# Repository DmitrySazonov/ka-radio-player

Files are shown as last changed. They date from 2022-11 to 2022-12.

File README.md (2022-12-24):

# ka-radio-player
This is a ka-radio player build project based on the ESP 32 and the UDA1334A DAC. The player uses the micro-usb connection as a power supply and has a mini-jack output for connecting to headphones or speakers.
There are 2 versions of cases in the project: for the screen 0.96" and 2.42".
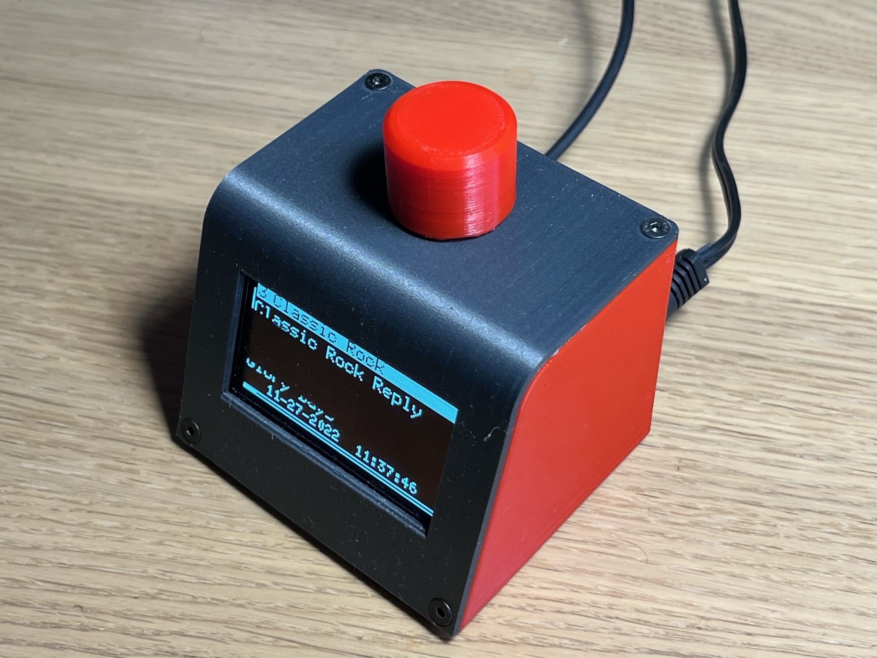
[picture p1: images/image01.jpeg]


V2 version for 2.42 display

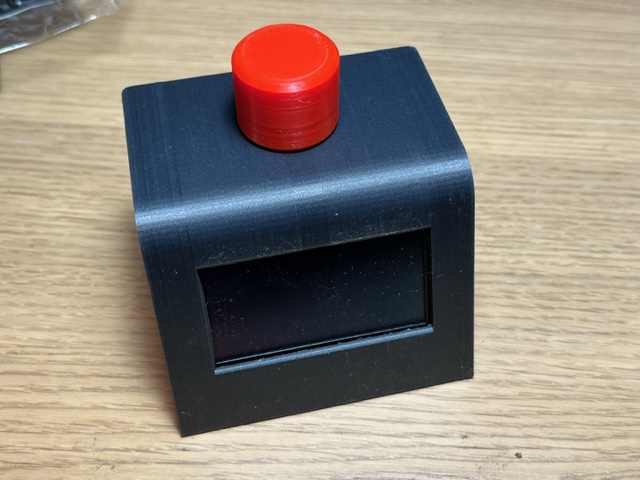
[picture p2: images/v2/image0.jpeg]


Demo video: https://youtu.be/d_xDyBW4TkM

## Components
- ESP 32 38P - https://sl.aliexpress.ru/p?key=cSeExr8
- UDA1334A DAC - https://sl.aliexpress.ru/p?key=o4eExBC
- Digital knob encoder - https://sl.aliexpress.ru/p?key=FfeExsv
- 2.42" OLED 4 pin display - https://sl.aliexpress.ru/p?key=MNKdxjn
or
0.96" OLED 4 pin display - https://sl.aliexpress.ru/p?key=2NeExj4
- 1K resistor

## Principal schema

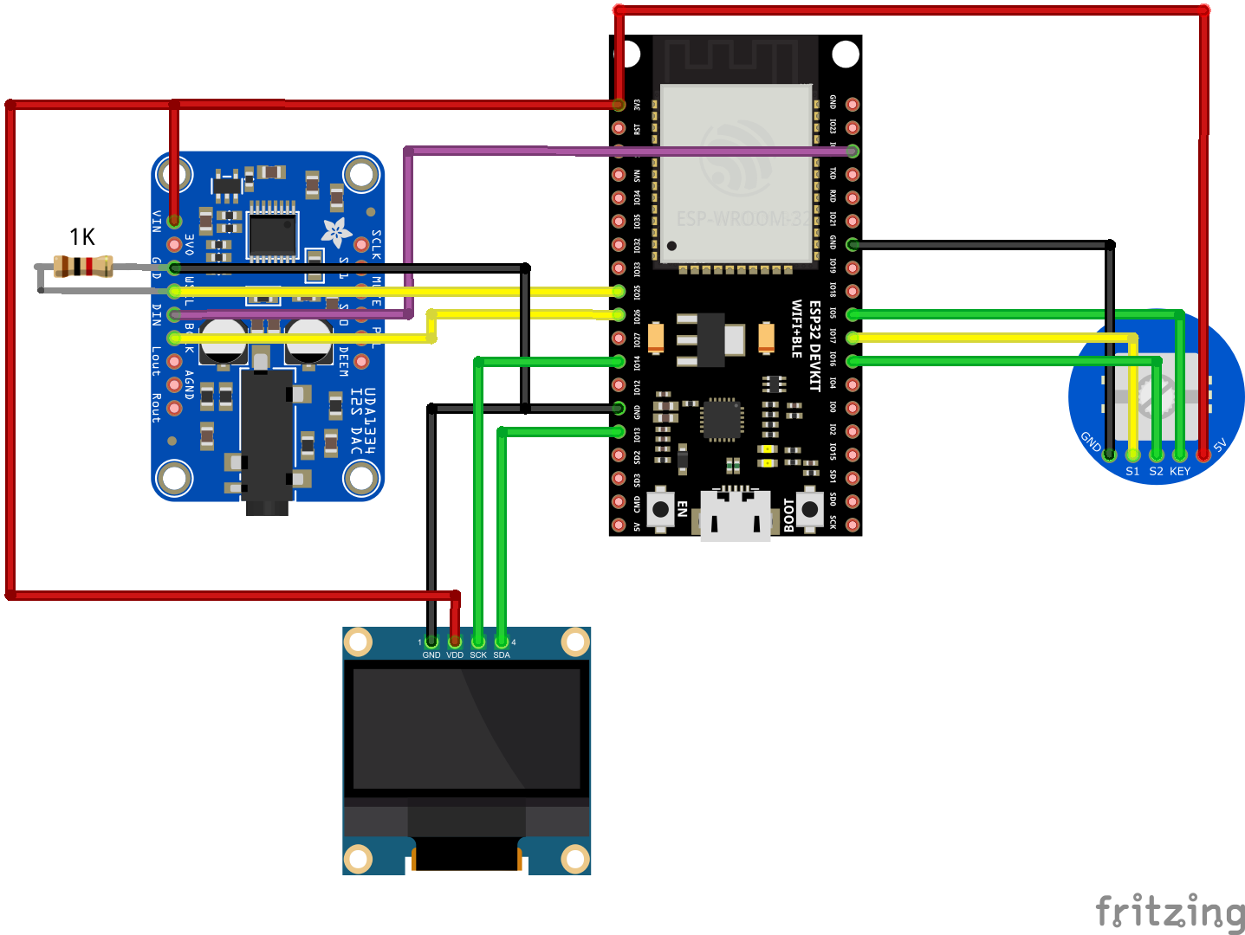
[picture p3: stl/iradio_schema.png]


### UDA1334A connection
| UDA1334A | ESP 32 |
|---|---|
| VIN | 3V3 |
| GND | GND |
| DIN | IO22 |
| WSEL | IO25 |
| BCLK | IO26 |

And add 1K resistor between **WSEL-GND**

### Display connection
| OLED Display | ESP 32 |
|---|---|
| GND | GND |
| VDD / VCC | 3V3 |
| SCK / SLC | IO14 |
| SDA | IO13 |

### Knob encoder connection
| Knob | ESP 32 |
|---|---|
| GND  | GND |
| S1 | IO17 |
| S2 | IO16 |
| KEY  | IO5 |
| 5V | 3V3 |

## 3D Print options

### Printing position
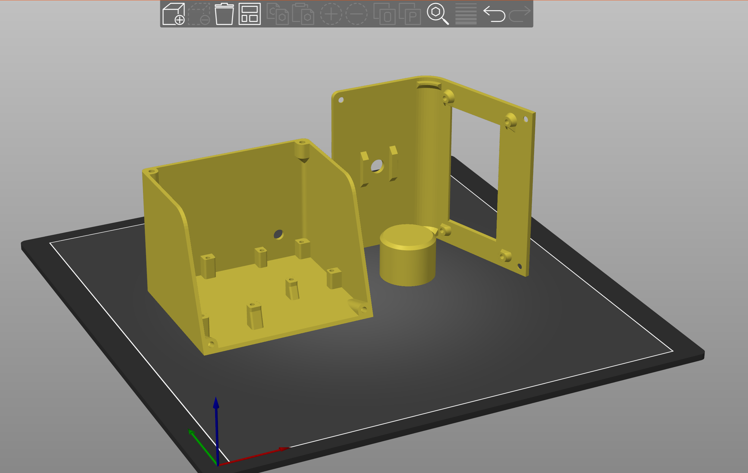
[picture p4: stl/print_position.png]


## Player assembly

The player body is printed on a 3-d printer. Models for printing are in the **/stl** folder, select models according to the size of the display.

For mount used:
- M2.5x5 mm bolt (8pc) to mount the boards
- M3x5 mm bolt (4pc) to mount the cap to case
- M2.5x5 mm bolt (2pc or 4pc) to mount display to cap

For v2 case mount:
- M2.5x5 mm bolt (10pc) to mount the boards and case

## Connection

- Plug the usb charger into the micro-usb. 

**IMPORTANT!** 
It is recommended to use a good quality power supply, especially for the 2.42" display version. I use BASEUS Compact Quick Charger USB+Type-C, 3A, 20W.

- Plug your headphones or speakers (with built-in amplifier) into the mini-jack connector.

## Configuration

The project is based on the firmware [karadio32](https://github.com/karawin/Ka-Radio32)

To flash it, just download the archive from the [release](https://github.com/karawin/Ka-Radio32/releases) page and flash it as specified in the [README](https://github.com/karawin/Ka-Radio32#first-use) of the project.

For more information search for karadio32 guides on the internet.

To configure the radio in the settings under *"SOUND SETTINGS"* set it to **I2S**

## Control
- Encoder rotation - volume control.
- Press the encoder knob to start/stop playing
- Press and turn the encoder to switch between stations.

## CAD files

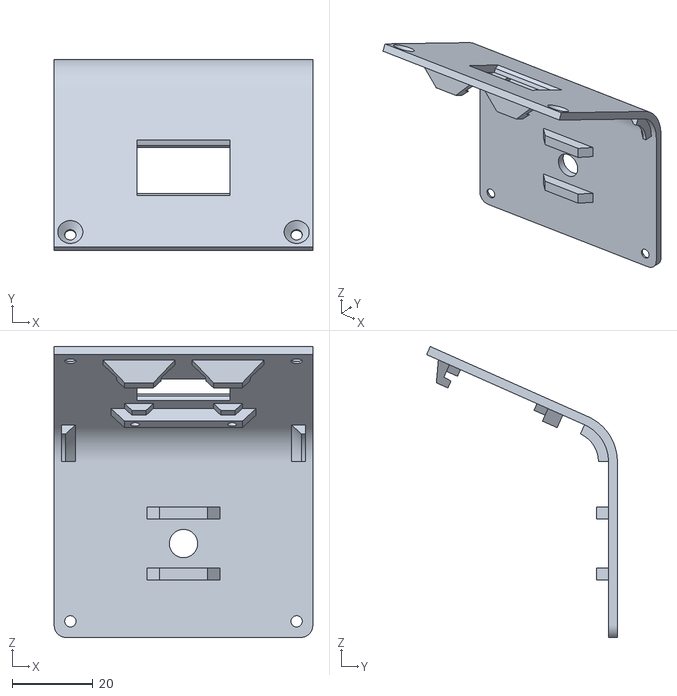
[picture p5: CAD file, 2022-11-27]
stl/0.96 display/cap_0.96.stl
64.0 x 47.2 x 72.0

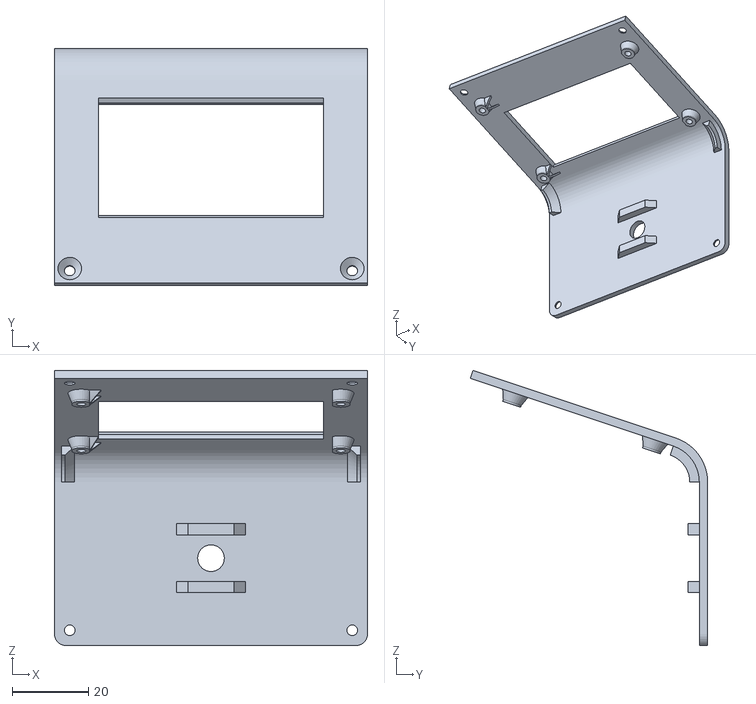
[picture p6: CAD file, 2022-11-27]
stl/2.42 display/cap_2.42.stl
82.0 x 62.2 x 72.1

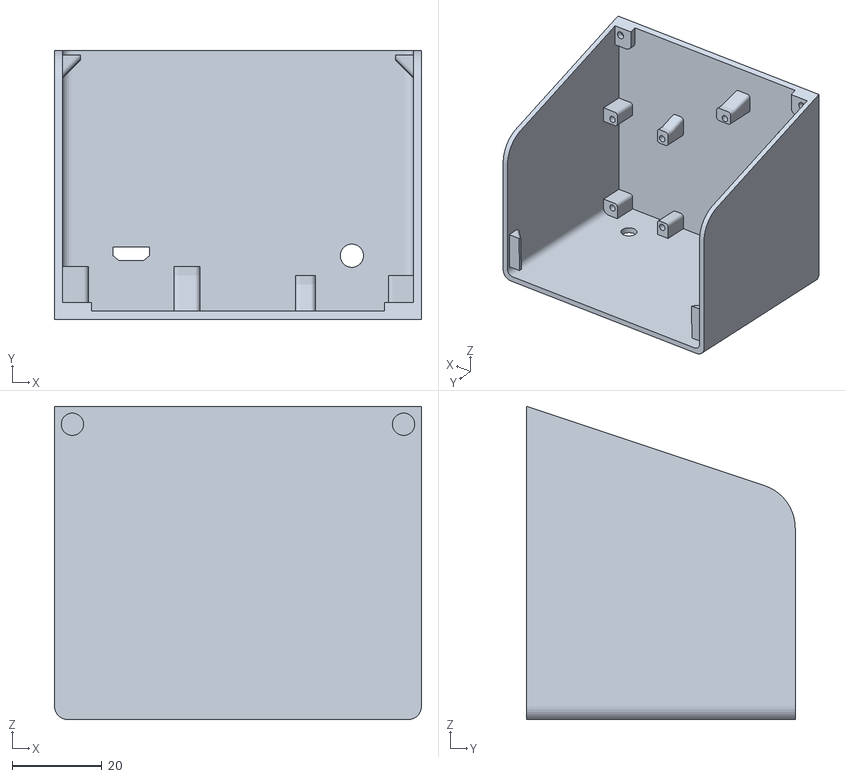
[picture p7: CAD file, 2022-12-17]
stl/2.42 v2/case_2.42_v2.stl
82.0 x 60.0 x 70.0

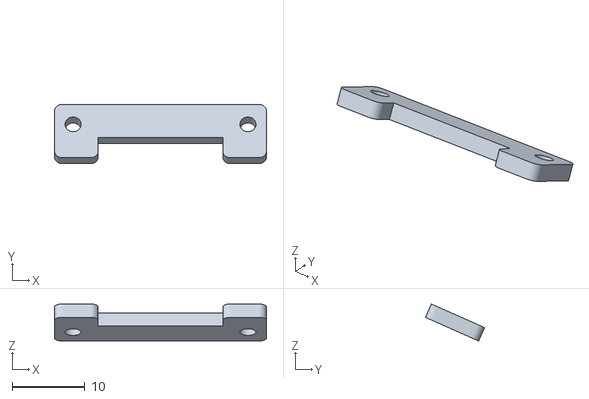
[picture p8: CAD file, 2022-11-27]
stl/0.96 display/display-holder_0.96.stl
29.1 x 8.12 x 5.08

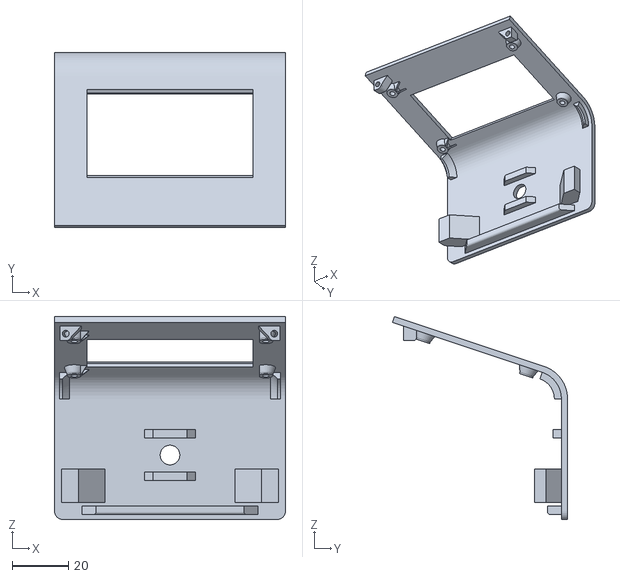
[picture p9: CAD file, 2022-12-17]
stl/2.42 v2/cap_2.42_v2.stl
82.0 x 62.2 x 72.1

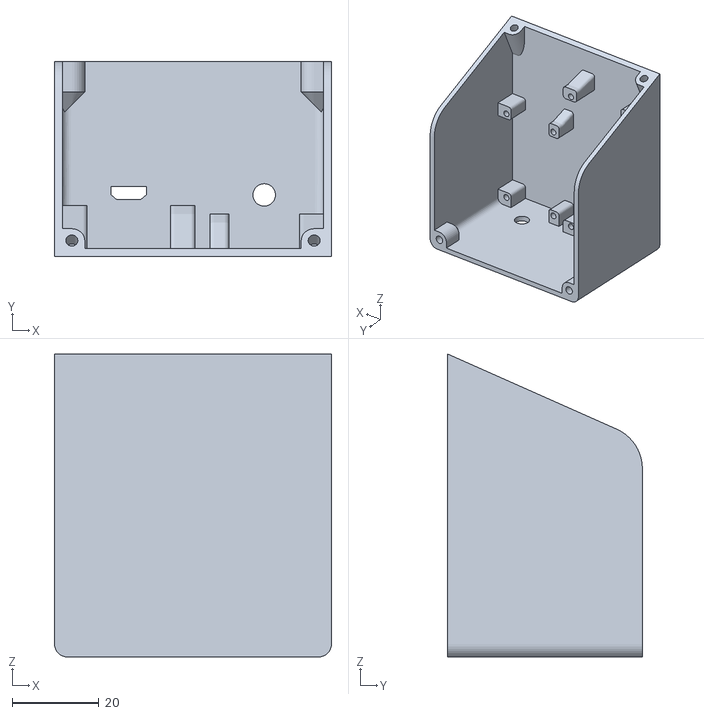
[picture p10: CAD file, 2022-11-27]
stl/0.96 display/case_0.96.stl
64.0 x 45.0 x 70.0

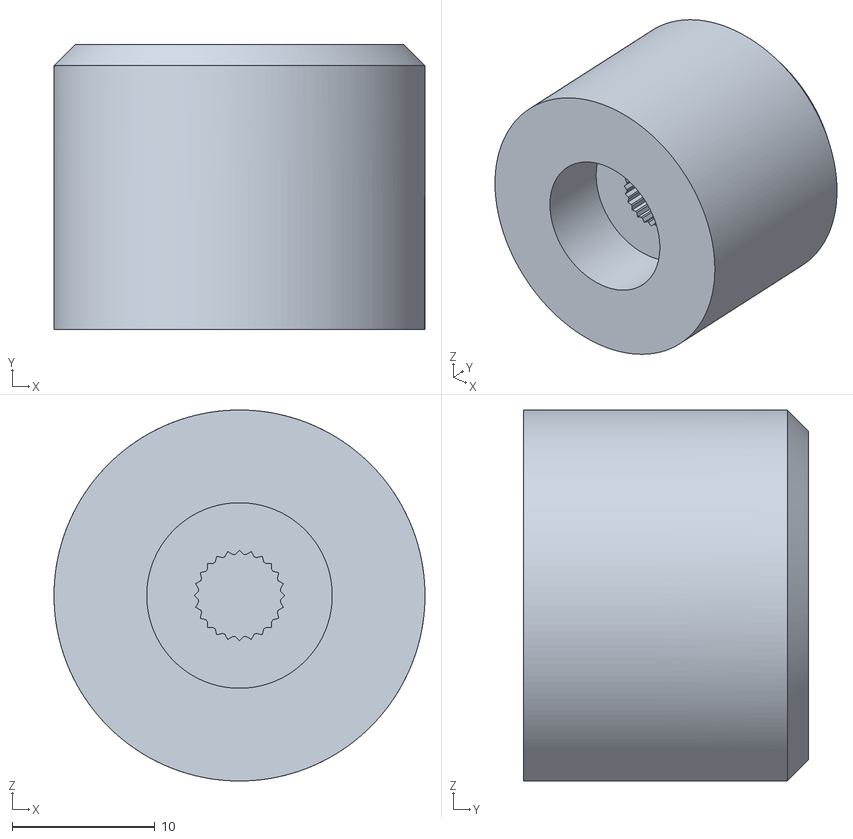
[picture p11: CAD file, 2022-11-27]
stl/2.42 v2/encoder-knob.stl
26.0 x 20.0 x 26.0

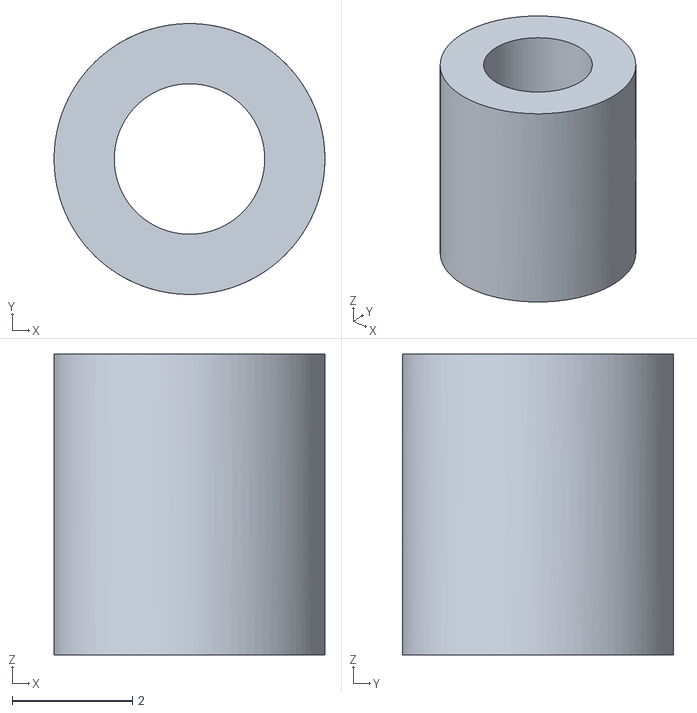
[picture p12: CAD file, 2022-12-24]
stl/washers/washer_2.5_5mm.stl
4.50 x 4.50 x 5.00

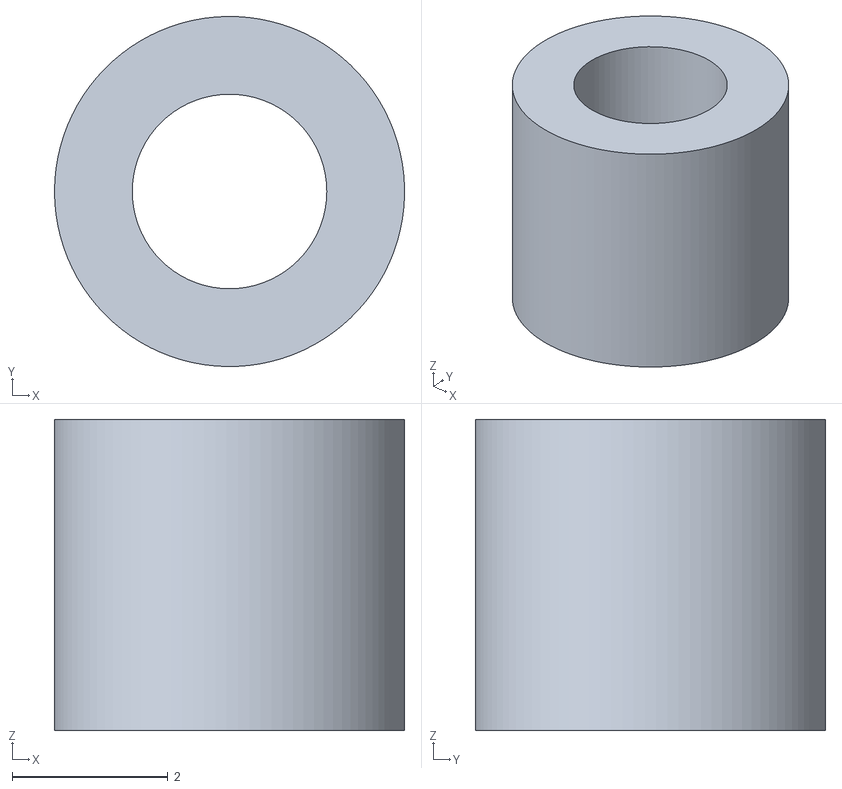
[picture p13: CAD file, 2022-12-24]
stl/washers/washer_2.5_4mm.stl
4.50 x 4.50 x 4.00

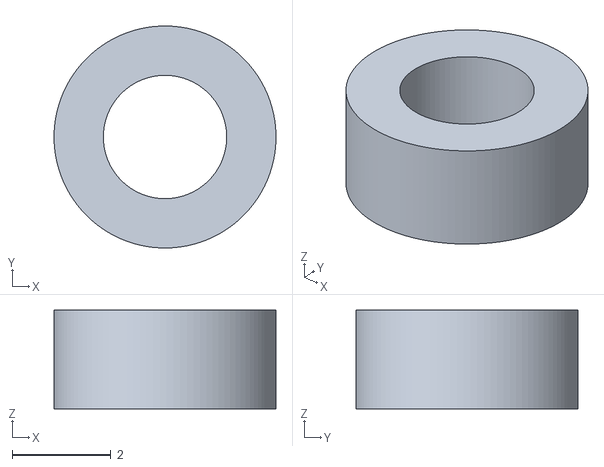
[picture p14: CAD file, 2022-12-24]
stl/washers/washer_2.5_2mm.stl
4.50 x 4.50 x 2.00

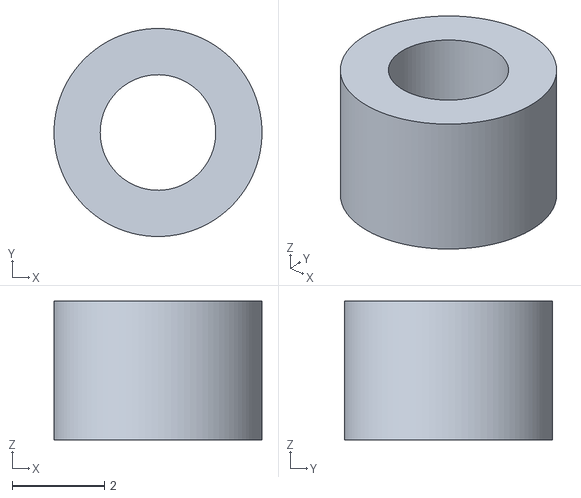
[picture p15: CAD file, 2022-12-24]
stl/washers/washer_2.5_3mm.stl
4.50 x 4.50 x 3.00

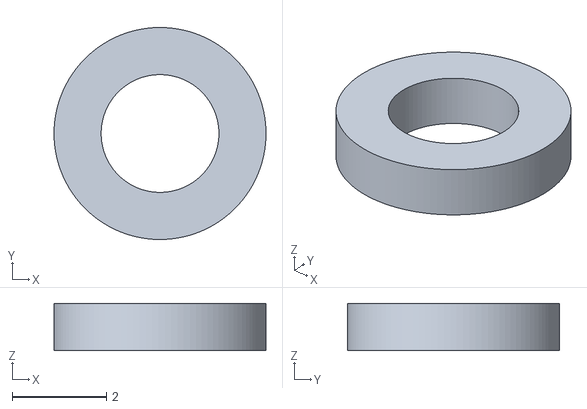
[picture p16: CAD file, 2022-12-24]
stl/washers/washer_2.5_1mm.stl
4.50 x 4.50 x 1.00

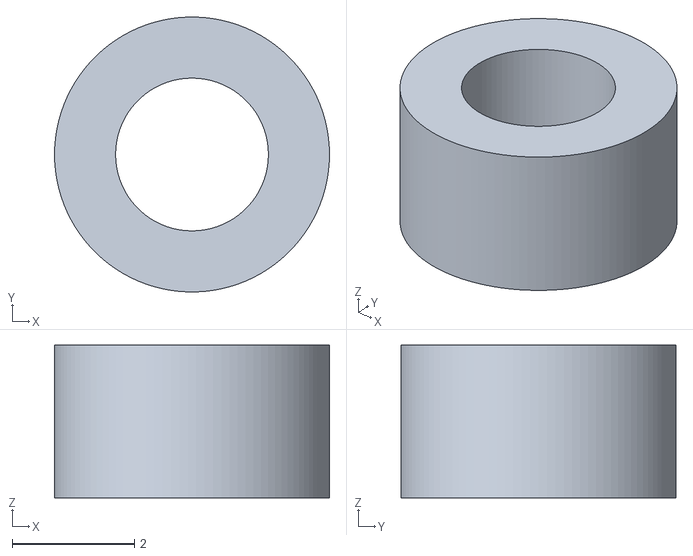
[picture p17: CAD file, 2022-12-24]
stl/washers/washer_2.5_2.5mm.stl
4.50 x 4.50 x 2.50

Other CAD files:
stl/2.42 display/case_2.42.stl

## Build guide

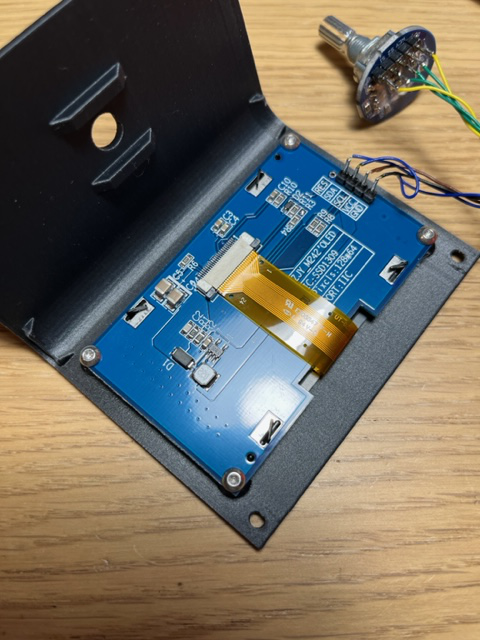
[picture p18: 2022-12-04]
assemble_images/assemble_display.jpg

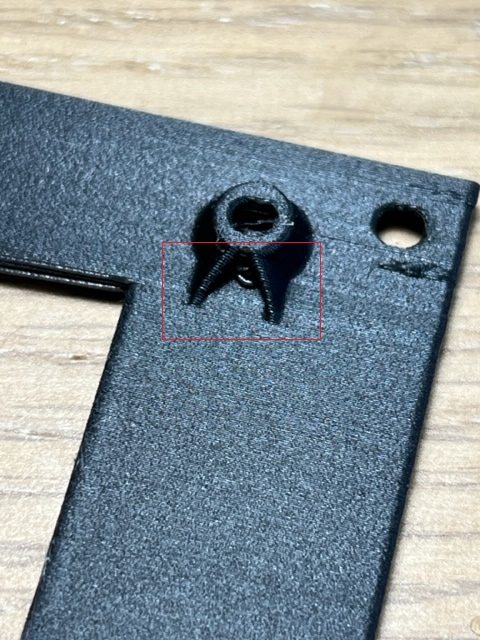
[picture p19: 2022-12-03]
assemble_images/post_cut.jpg

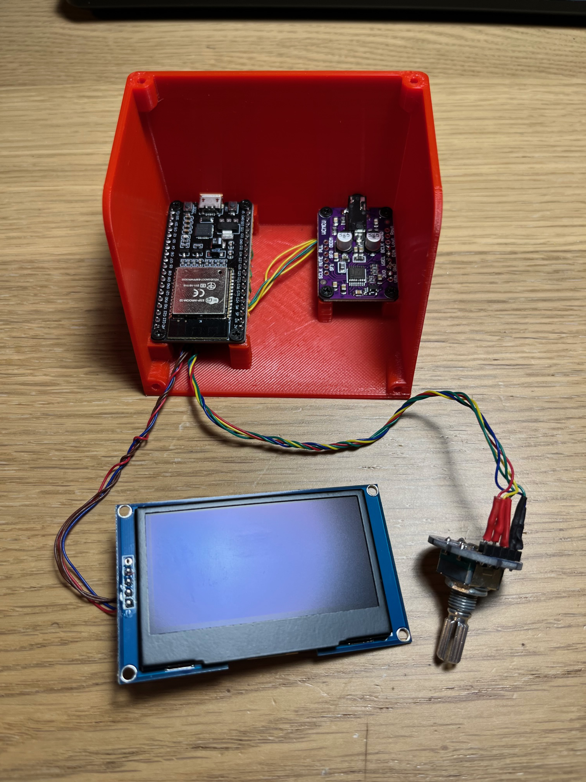
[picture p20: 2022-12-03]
assemble_images/assemble.jpg

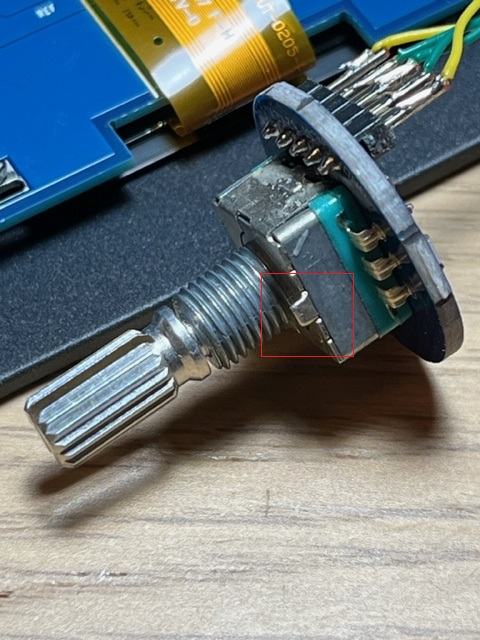
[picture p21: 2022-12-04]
assemble_images/cut_knob.jpg

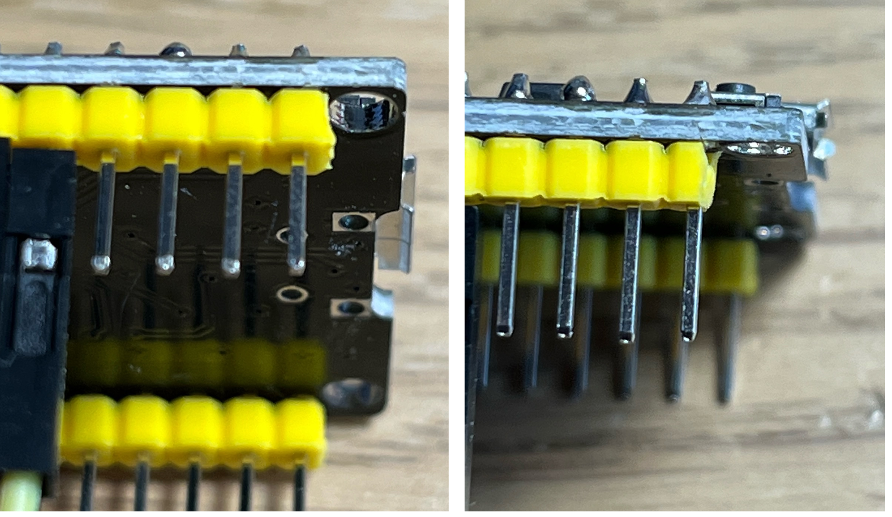
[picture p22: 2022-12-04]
assemble_images/esp_32_cut.png

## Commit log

2022-12-01 add img of print position
2022-12-01 add description of printing
2022-12-03 add postprint cut
2022-12-03 add assemble.jpg
2022-12-04 add assemble images
2022-12-17 add v2 version
    [cap_2.42_v2.stl, case_2.42_v2.stl, encoder-knob.stl]
2022-12-24 add washers stl
    [washer_2.5_1mm.stl, washer_2.5_2.5mm.stl, washer_2.5_2mm.stl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]
